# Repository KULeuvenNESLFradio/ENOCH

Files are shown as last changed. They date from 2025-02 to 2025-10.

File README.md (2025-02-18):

# ENOCH: ENabling On-body Network Contention Handling

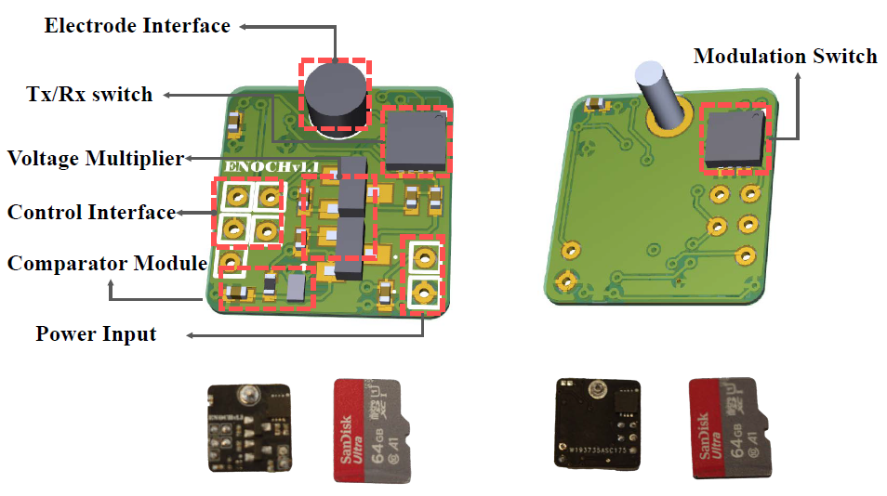
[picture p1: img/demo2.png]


## 📄 Citation
If you use this work, please cite:
ENOCH: ENabling On-body Network Contention Handling  
Mengyao Liu, Jonathan Oostvogels, Bingwu Fang, Sam Michiels, Haoxiang Ma, Yang Yang, and Danny Hughes  
In *Proceedings of the IEEE International Conference on Pervasive Computing and Communications (PerCom)*,  
Washington, DC, USA, March 17–21, 2025. IEEE, 2025.

### 📚 BibTeX
```bibtex
@inproceedings{Liu2025ENOCH,
  author       = {Mengyao Liu and Jonathan Oostvogels and Bingwu Fang and Sam Michiels and Haoxiang Ma and Yang Yang and Danny Hughes},
  title        = {{ENOCH: ENabling On-body network Contention Handling}},
  booktitle    = {Proceedings of the IEEE International Conference on Pervasive Computing and Communications (PerCom)},
  year         = {2025},
  organization = {IEEE},
  address      = {Washington, DC, USA},
  month        = {March},
  pages        = {17--21},
  doi          = {10.1109/PerCom2025.XXXX}  % 请在 DOI 可用时添加
}
```

## Overview
ENOCH is a low-latency, capacitively coupled on-body communication system optimized for ultra-low-power operation. It employs off-the-shelf components and is programmed on an **Arduino Due**, making it accessible for researchers and developers interested in **body area networks (BANs)**.

This repository contains all necessary files to **replicate and extend** our implementation, including:
- Hardware schematics and PCB design files
- Arduino source code and API documentation
- Experimental setups and results

## 🛠 Hardware Setup
### Component Specifications
- **Greinacher Voltage Multiplier:** A capacitive charge-pump circuit optimized for RF signal rectification.
- **Comparator with RC Low-Pass Filter:** Dynamically adjusts thresholds to enhance noise immunity.
- **RF Switches:** ADG918 (TX/RX switching) and ADG902 (OOK modulation).
- **Arduino Due:** Serves as the processing unit for signal transmission and reception.

### PCB Design
The **hardware folder** contains:
- **Schematics** (`.sch`) and **PCB layout files** (`.pcbdoc`)
- **Gerber files** for manufacturing
- **Altium Designer project files**

Manufacturing can be done via [PCBWay](https://www.pcbway.com/). We recommend using the **evaluation board** before transitioning to the miniaturized version.

## 💻 Software Setup
### Requirements
1. Install the [Arduino IDE](https://www.arduino.cc/en/software)
2. Download this repository
3. Connect **Arduino Due** via USB

### Compiling & Uploading
1. Open `Arduino IDE`
2. Select **Arduino Due (Programming Port)** under `Tools → Board`
3. Open `enochtx.ino` or `enochrx.ino`
4. Click `Verify (✔)` and then `Upload (⬆)`
5. Open `Serial Monitor` to view output

## 📡 ENOCH API
To use ENOCH with an **Arduino Due**, define the following pins:
```cpp
#define ENOCHTxCarrier 7     // Tx carrier frequency pin
#define ENOCHOOKSW 2         // Modulation (OOK) Switch pin
#define ENOCHRxGPIO 6        // Rx GPIO pin
#define ENOCHTxRxSwitch 8    // Switch for Tx/Rx mode
```
### Available Functions
```cpp
void Send_preamble(int cycles); // Transmit preamble
void Send_bytes(byte bytex[]);  // Send data bytes
void Read_bytes(byte load[]);   // Read received bytes
boolean checkRxStatus();        // Check channel availability
```

## ⚡ Experiments 
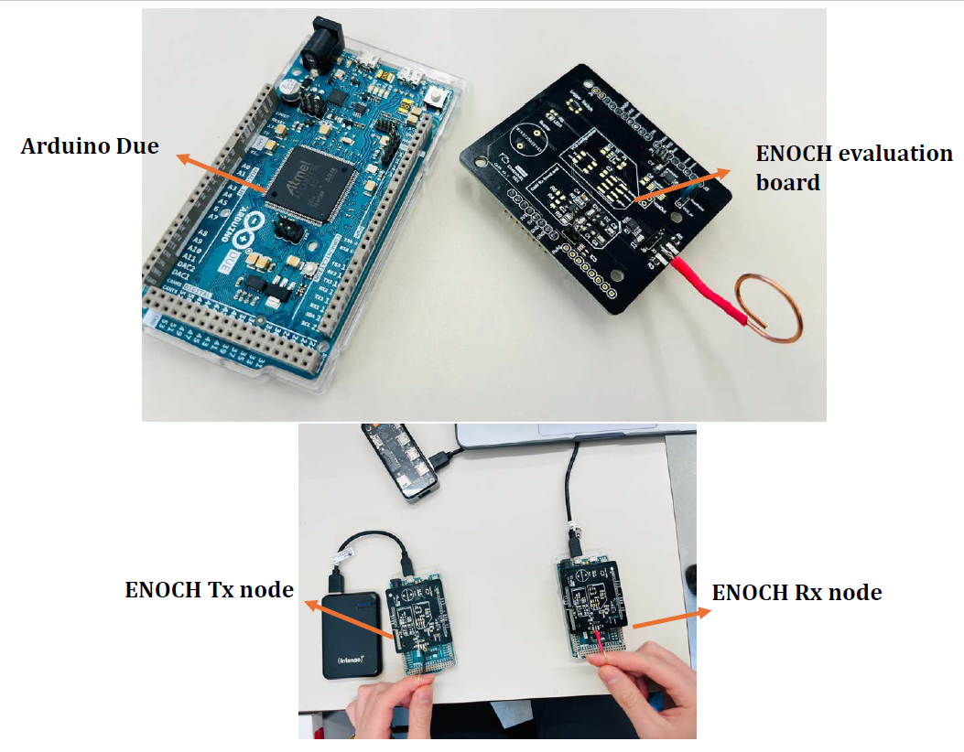
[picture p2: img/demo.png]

### 1️⃣ Single Transmitter & Receiver
- One **ENOCH board** transmits, the other receives.
- The receiver outputs data via `Serial Monitor`.
- **Evaluate packet delivery reliability** by testing different body placements (wrist, arm, ankle).

### 2️⃣ Multi-Node Contention
- Multiple nodes attempt to transmit simultaneously.
- A **hardware trigger button** ensures synchronized transmission.
- Transmission priority is determined by `Send_preamble(int cycles)`.

## 📂 Repository Structure
```
ENOCH/
├── Hardware/       # PCB schematics, Gerber files, and Altium projects
├── Software/       # Arduino source code for Tx and Rx
├── Docs/           # Additional documentation and experiments
├── README.md       # This file
```

## 📬 Contact & Contribution
Feel free to **open an issue** for questions or contributions. We welcome pull requests to improve the ENOCH project!

📧 Contact: [mengyao.liu@kuleuven.be](mailto:mengyao.liu@kuleuven.be)

## 🔗 Links
- 🔬 **Paper:** [PerCom 2025](https://www.percom.org/)
- 📖 **GitHub Repo:** [ENOCH Project](https://github.com/KULeuvenNESLFradio/ENOCH)
- 🏭 **PCB Manufacturing:** [PCBWay](https://www.pcbway.com/)

---
🚀 *Bringing robust on-body network contention handling to ultra-low-power systems!*

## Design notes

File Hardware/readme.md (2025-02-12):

### Component Specifications
- **Greinacher Voltage Multiplier:** A capacitive charge-pump circuit optimized for RF signal rectification.
- **Comparator with RC Low-Pass Filter:** Dynamically adjusts thresholds to enhance noise immunity.
- **RF Switches:** ADG918 (TX/RX switching) and ADG902 (OOK modulation).
- **Arduino Due:** Serves as the processing unit for signal transmission and reception.

### PCB Design
The **hardware folder** contains:
- **Schematics** (`.sch`) and **PCB layout files** (`.pcbdoc`)
- **Gerber files** for manufacturing
- **Altium Designer project files**

### Main Components on the ENOCH Transceiver
| **CAIN Prototype Components** | **Part Number**  | **Purchase Link** |
|---:|:---:|:---:|
| Rectifying Diodes | SMS7630-005LF | [Digi-Key](https://www.digikey.com/en/products/detail/???/???) |
| RF SPDT Switche | ADG918 | [Mouser](https://www.mouser.com/ProductDetail/???/???) |
| RF SPST Switche | ADG902 | [Mouser](https://www.mouser.com/ProductDetail/???/???) |
| Analog Comparator | TLV7031 | [Mouser](https://www.mouser.com/ProductDetail/???/???) |
---
Manufacturing can be done via [PCBWay](https://www.pcbway.com/). We recommend using the **evaluation board** before transitioning to the miniaturized version.

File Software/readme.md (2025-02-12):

# ENOCH Wireless Communication Setup

## 1. Single Transmitter, Single Receiver
Two ENOCH boards are used, each programmed for either transmission (`ENOCHtx.ino`) or reception (`ENOCHrx.ino`).

- The RX board is worn on the finger and connected to a laptop via USB to provide serial data output.
- To assess packet delivery ratio reliability, the TX board can be positioned at various body locations (e.g., wrist, arm, ankle).

## 2. Multiple Transmitters, Single Receiver
In this setup, an additional Arduino trigger board is required to synchronize transmissions across multiple ENOCH nodes.

### Required Components
- ENOCH nodes
- Arduino trigger board
- A button (for generating interrupt signals)

### Steps for Multi-Node Transmission
1. **Set Up the Trigger**
   - Connect a button to the Arduino trigger board and ENOCH nodes.
   - Refer to `trigger_gpio.ino` for implementation details.

2. **Configure ENOCH Transceivers**
   - Load the firmware to enable transmission upon receiving an interrupt signal.
   - Press the button to synchronize transmissions across multiple nodes.

3. **Adjust Priorities (if needed)**
   - Modify `Send_preamble(int cycles)` to assign more cycles to higher-priority nodes.

4. **Test and Verify**
   - Read the received data from the RX board.
   - Check the serial port for transmission logs to validate successful communication.

### Example Code: Button-triggered Transmission
```cpp
#define buttonPin 53 

void buttonISR() {
    buttonPressed = true;
    FristTrigger = true;
    digitalWriteDirect(ENOCHTxRxSwitch, LOW);
    Send_preamble(x);
}  

if (buttonPressed) { 
    do {
        if (checkRxStatus() != RX_BUSY) {
            if (FristTrigger) {
                digitalWriteDirect(ENOCHTxRxSwitch, LOW); 
                Send_bytes('0', 'N', 'O', 'D', 'E', '0', '0');
                digitalWriteDirect(ENOCHTxRxSwitch, HIGH);
                FristTrigger = false;
                buttonPressed = false;
            } else {
                FristTrigger = false;
                digitalWriteDirect(ENOCHTxRxSwitch, LOW);
                Send_preamble(10);
                if (checkRxStatus() != RX_BUSY) {
                    digitalWriteDirect(ENOCHTxRxSwitch, LOW); 
                    Send_bytes('0', 'N', 'O', 'D', 'E', '0', '0');
                    digitalWriteDirect(ENOCHTxRxSwitch, HIGH);
                    buttonPressed = false;
                }
            }
        } 
    } while (buttonPressed);
    Serial.println("Finish sending packets");
}
```

---
For more details, refer to the implementation files (`ENOCHtx.ino`, `ENOCHrx.ino`, `trigger_gpio.ino`).

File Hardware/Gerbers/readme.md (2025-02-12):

-  **CaINV2.2**: Our evaluation board design.
-  **BodyCaINv0.1Gerber**: Adapted to the GEMMA V2 interface.
-  **ENOCHv1.0**: The most miniaturized design.
-  **GerberBodyCaINseedv0.2**: Adapted to the Seeed Studio nRF52840

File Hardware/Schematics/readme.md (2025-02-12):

- **CaINv2.2**: Our evaluation board design.
- **bodyCaINCir**: Adapted to the GEMMA V2 interface.
- **ENOCHv1.0**: The most miniaturized design.

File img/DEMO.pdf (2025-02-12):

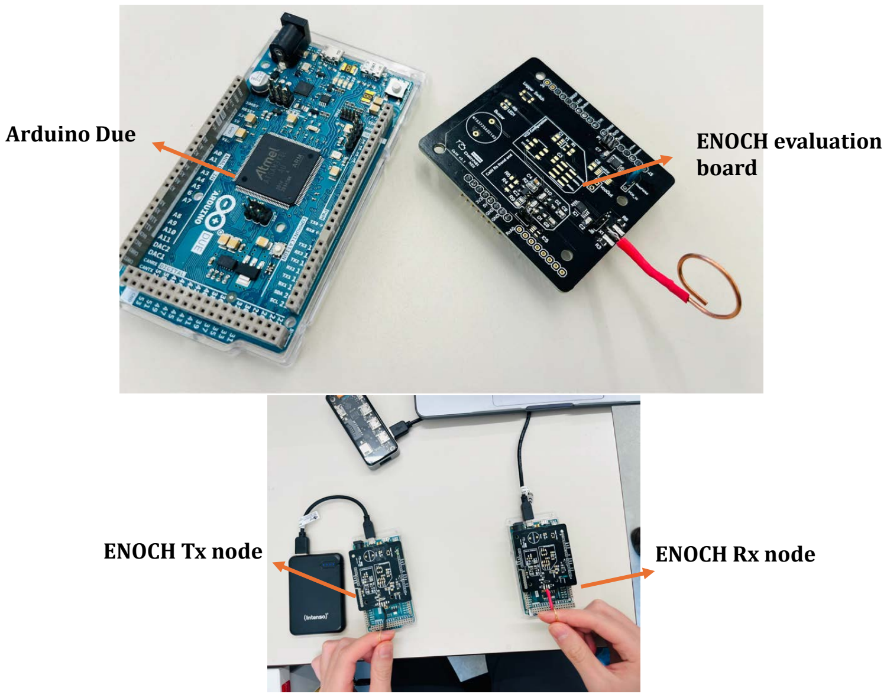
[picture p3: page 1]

Arduino Due | ENOCH evaluation board
ENOCH Tx node | ENOCH Rx node

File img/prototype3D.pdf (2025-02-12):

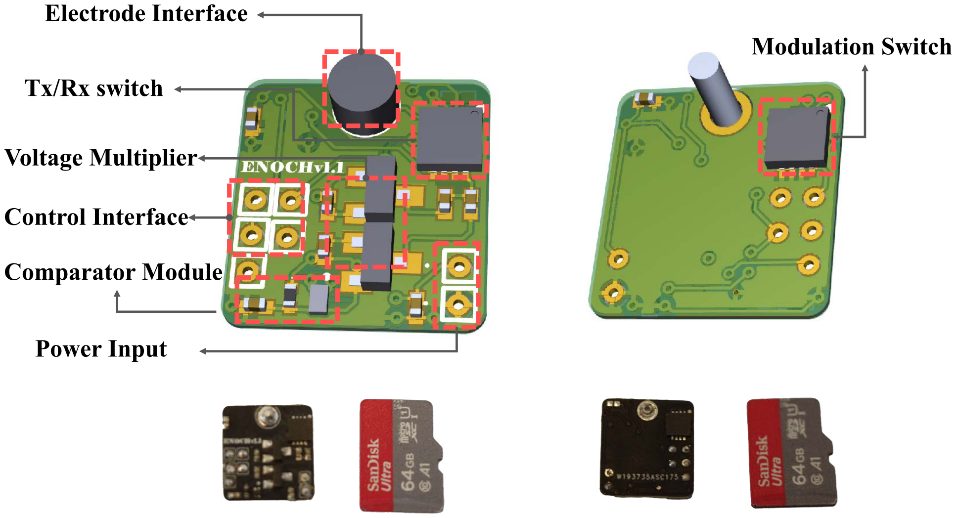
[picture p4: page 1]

Electrode Interface

Tx/Rx switch

Control Interface

Voltage Multiplier

Power Input

Comparator Module

Modulation Switch

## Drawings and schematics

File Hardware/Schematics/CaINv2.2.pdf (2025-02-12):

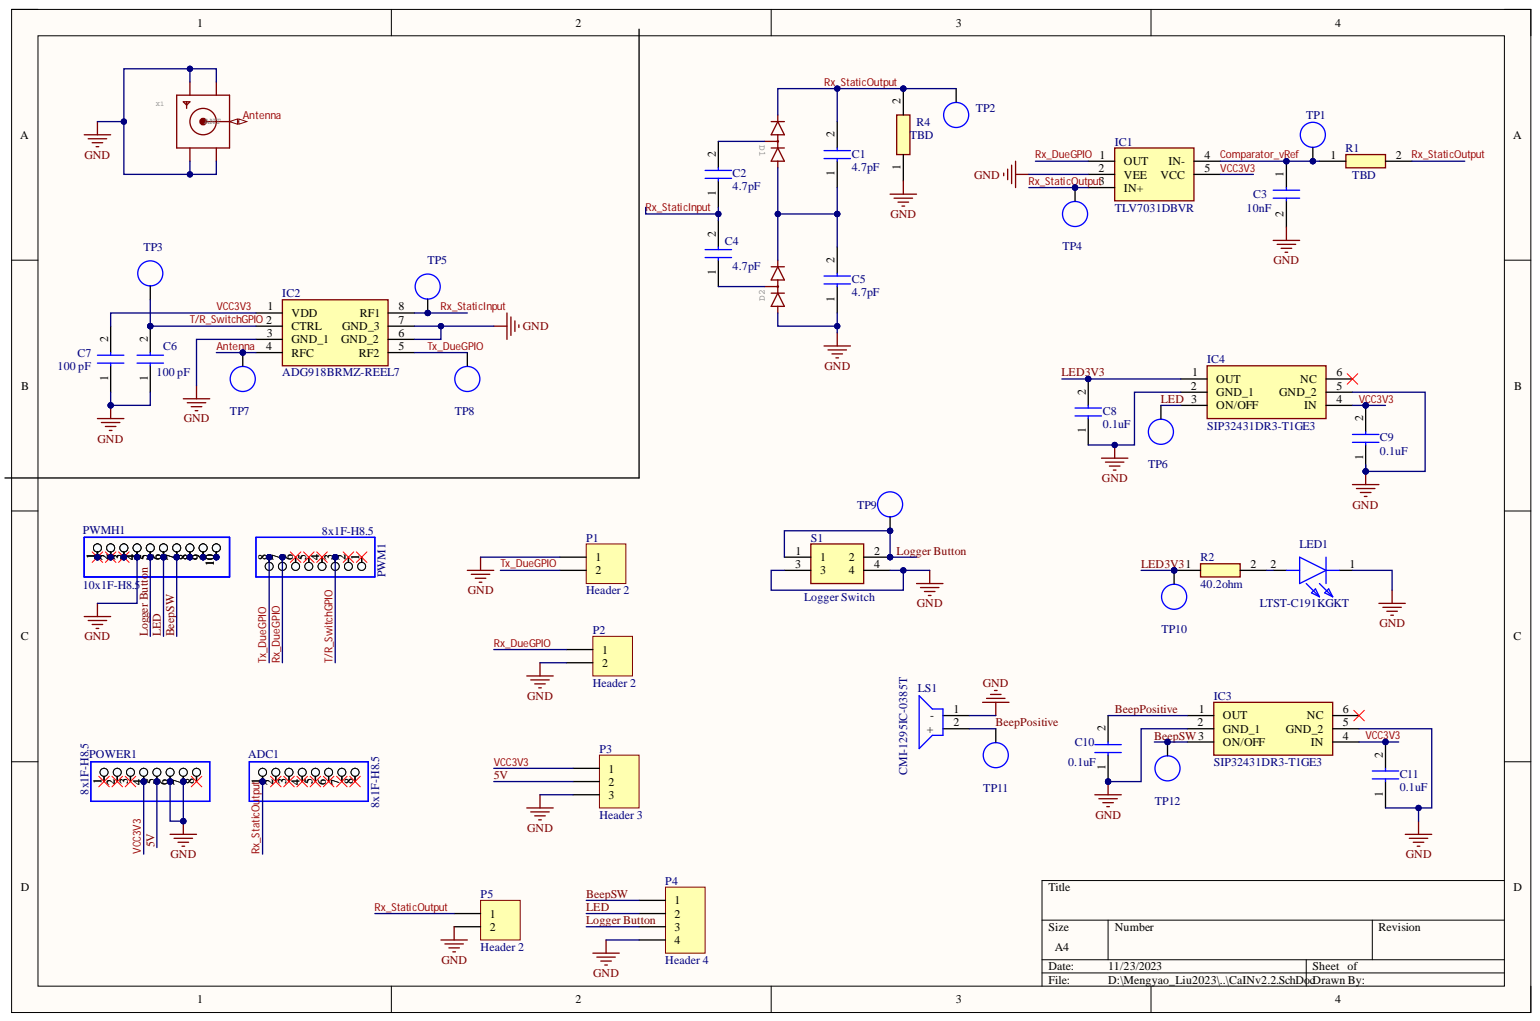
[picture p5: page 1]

GND_1 3 | Tx_DueGPIO

Antenna | RFC 4

GND_1 2

BeepSW | ON/OFF 3 | VCC3V3 C11

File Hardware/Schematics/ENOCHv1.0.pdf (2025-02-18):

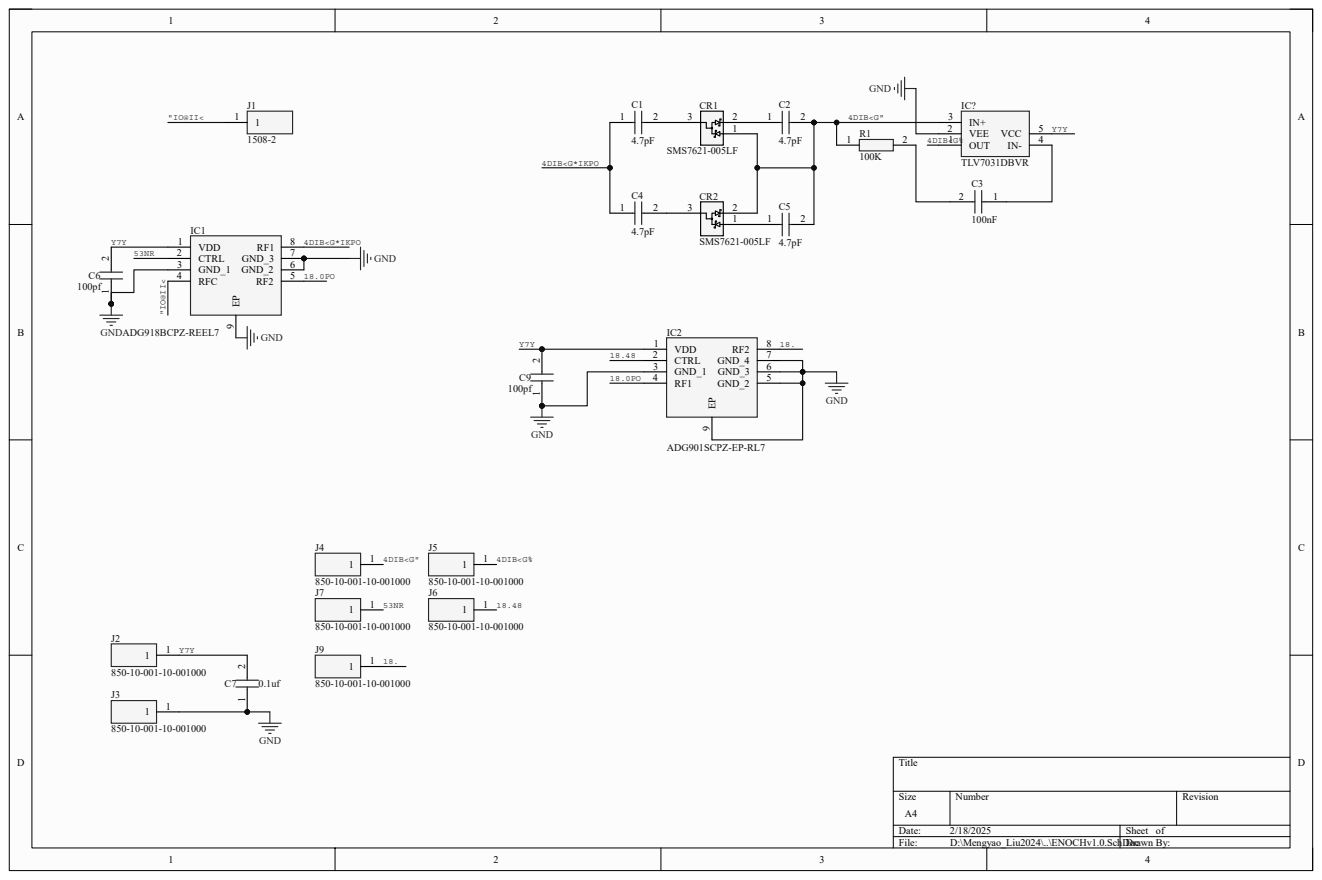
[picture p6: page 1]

Size A4 | Number | Revision

Date: 2/18/2025 | Sheet of
File: D:\Mengyao_Liu2024\..\ENOCHv1.0.SchDoc Drawn By:

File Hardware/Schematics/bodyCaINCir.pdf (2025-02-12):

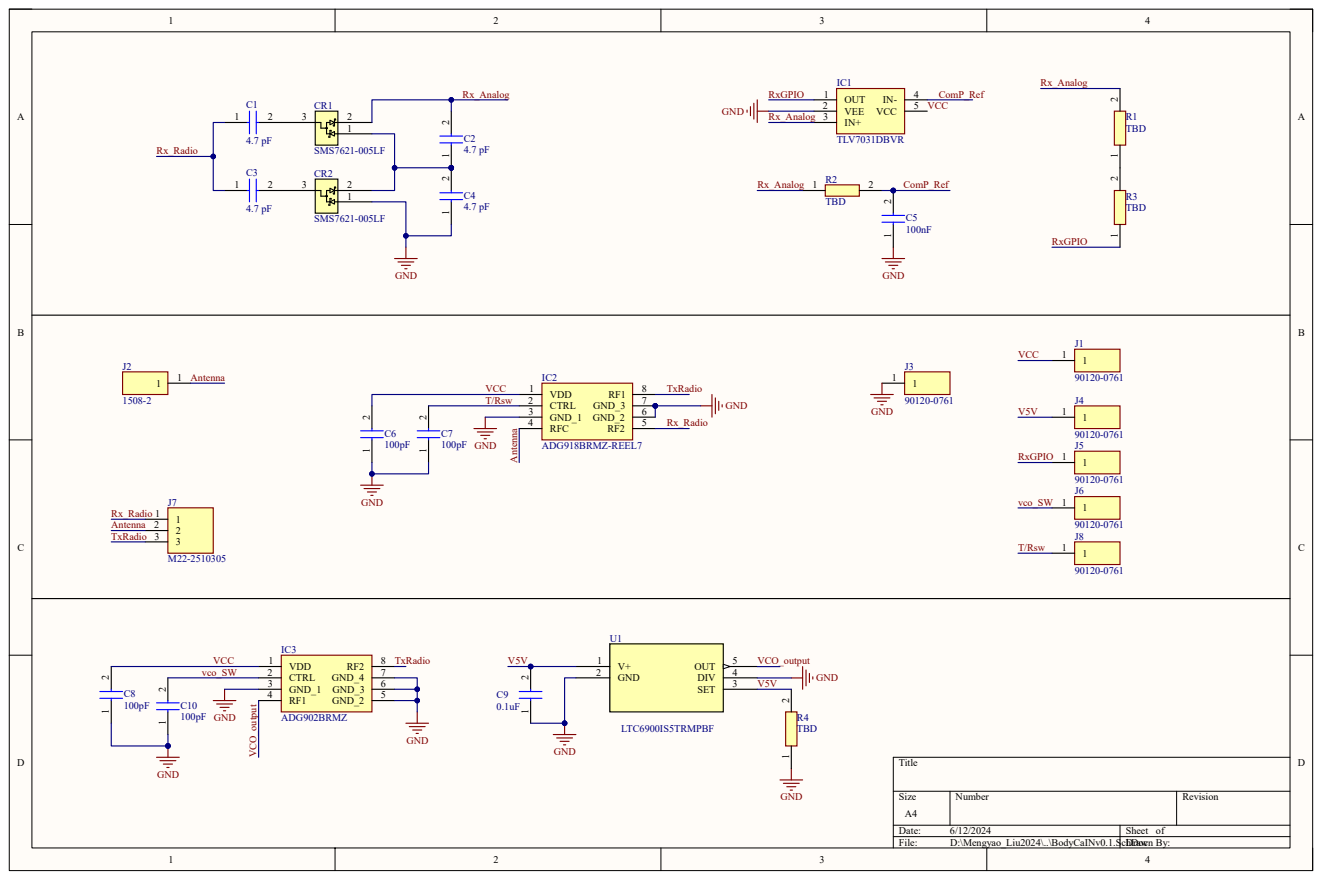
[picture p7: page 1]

Size A4 | Number | Revision

Date: 6/12/2024 | Sheet of
File: D:\Mengyao_Liu2024\..\BodyCaINv0.1.SchDoc Drawn By:

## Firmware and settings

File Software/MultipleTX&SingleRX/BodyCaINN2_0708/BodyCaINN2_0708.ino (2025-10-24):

#define CaINTxGPIO PIO_PC23B_PWML6  
#define CaINTxRxSwitch 8 
#define CaINOPWMSW 2
#define CaINRxGPIO 6 
#define buttonPin 53
#define OnRadioFlag HIGH
#define OffRadioFlag LOW

/* Generate the PWM (12 MHz) */
const uint8_t BitRate20khz = 80;
const uint8_t Period12Mhz = 2;
const uint8_t Duty12Mhz = 1;

volatile bool buttonPressed = false; 
volatile bool firstTrigger = false;
volatile uint8_t Preambletimes = 0;
byte Address_Node[8] = { 0, 0, 1, 0, 0, 1, 0, 1 };
volatile boolean TxState ;

inline boolean digitalWriteDirect(int pin, boolean val) {
  if (val) g_APinDescription[pin].pPort -> PIO_SODR = g_APinDescription[pin].ulPin;
  else    g_APinDescription[pin].pPort -> PIO_CODR = g_APinDescription[pin].ulPin;
  if (val == HIGH) return OnRadioFlag;
  else return OffRadioFlag;
}

inline int digitalReadDirect(int pin) {
  return !!(g_APinDescription[pin].pPort -> PIO_PDSR & g_APinDescription[pin].ulPin);
}


// Generate the PWM (12 MHz) as Carrier Frequency From 38.6.5 PWM Controller Operations //
void Enable_CarrierPWM(uint8_t Period, uint8_t Duty) {
  /* Activate clock for PWM controller from PMC, PWM ID =36 ->*/
  REG_PMC_PCER1 = 1 << 4;
  // Activate peripheral functions for pin -> Datasheet 31.7.2 & 31.5.2&3)
  REG_PIOC_PDR |= CaINTxGPIO;
  REG_PIOC_ABSR |= CaINTxGPIO;
  /*   ----------------The following is for configure the PWM ----------------*/
  //38.7.1 Select the MCK (Master clock 84Mhz)
  REG_PWM_CLK = 0;
  //38.7.37 PWM Channel Mode Register PWM channel 6 (pin7) -> (CPOL = 0)  left-aligned
  REG_PWM_CMR6 = 0 << 9;
  //38.7.40 PWM Channel Period Register (16 bits -> Period / 84 = Frequency Output )
  REG_PWM_CPRD6 = Period;
  //38.7.38 PWM Channel Duty Cycle Register
  REG_PWM_CDTY6 = Duty;
  //38.7.2 PWM Enable Register
  REG_PWM_ENA = 1 << 6;
  //  return OnRadioFlag;
}

void Ascii_to_BinaryAarray(char ascii, uint8_t arr[8]) {
  //Serial.print(ascii);
  byte mask = 0b00000001;
  for (int i = 0; i < 8; i++) {
    arr[i] = ascii & mask;
    arr[i] = arr[i] >> i;
    mask = mask << 1;
  }
}

/*send  HIGH LOW edges to synchronize with the receptor*/
void Send_sync(int cycles) {
  //sending a sync signal
  for (byte i = 0; i < cycles; i++) {
    digitalWriteDirect(CaINOPWMSW, HIGH);
    delayMicroseconds(BitRate20khz);
    digitalWriteDirect(CaINOPWMSW, LOW);
    delayMicroseconds(BitRate20khz);
  }
  digitalWriteDirect(CaINOPWMSW, HIGH);
}

///*send  HIGH LOW edges to synchronize with the receptor*/
void Send_preamble(int cycles) {
  for (byte i = 0; i < cycles; i++) {
    digitalWriteDirect(CaINOPWMSW, HIGH);
    delayMicroseconds(BitRate20khz/2);
    digitalWriteDirect(CaINOPWMSW, LOW);
    delayMicroseconds(BitRate20khz/2);
  }
  digitalWriteDirect(CaINOPWMSW, LOW);
}


/*send a byte but without sync; state is the current state of the ouput line*/
boolean Send_load(byte Databits[], boolean Bitstate) {
  for (byte i = 0; i < 8; i++) {
    //Serial.print(start[i]);
    if (Databits[i] == 1) {
      if (Bitstate == LOW)
      {
        delayMicroseconds(BitRate20khz);
        Bitstate = digitalWriteDirect(CaINOPWMSW, HIGH);
      }
      else 
      {
        delayMicroseconds(BitRate20khz / 2);
        digitalWriteDirect(CaINOPWMSW, LOW);
        delayMicroseconds(BitRate20khz / 2);
        Bitstate = digitalWriteDirect(CaINOPWMSW, HIGH);
      }
    }
    else  
    {
      if (Bitstate == LOW)
      {
        delayMicroseconds(BitRate20khz / 2);
        digitalWriteDirect(CaINOPWMSW, HIGH);
        delayMicroseconds(BitRate20khz / 2);
        Bitstate = digitalWriteDirect(CaINOPWMSW, LOW);
      }
      else  
      {
        delayMicroseconds(BitRate20khz);
        Bitstate = digitalWriteDirect(CaINOPWMSW, LOW);
      }
    }
  }
  return Bitstate;
}

/*send a sync signal + a start byte + load ; load is an array of 8 bit, no more no less !!*/
void Send_bytes(byte byteload0, byte byteload1, byte byteload2, byte byteload3, byte byteload4, byte byteload5, byte byteload6) {

  byte Dataload0Arr[8];
  byte Dataload1Arr[8];
  byte Dataload2Arr[8];
  byte Dataload3Arr[8];
  byte Dataload4Arr[8];
  byte Dataload5Arr[8];
  byte Dataload6Arr[8];

  Ascii_to_BinaryAarray(byteload0, Dataload0Arr);    //change ascii code to bits array
  Ascii_to_BinaryAarray(byteload1, Dataload1Arr);    //change ascii code to bits array
  Ascii_to_BinaryAarray(byteload2, Dataload2Arr);
  Ascii_to_BinaryAarray(byteload3, Dataload3Arr);
  Ascii_to_BinaryAarray(byteload4, Dataload4Arr);
  Ascii_to_BinaryAarray(byteload5, Dataload5Arr);
  Ascii_to_BinaryAarray(byteload6, Dataload6Arr);

  // Send 32 cycles for preamble
  Send_sync(10);
  //line must be high after sync
  TxState = HIGH;
  TxState = Send_load(Address_Node, TxState);
  TxState = HIGH;
  TxState = Send_load(Dataload0Arr, TxState);
  TxState = Send_load(Dataload1Arr, TxState);
  TxState = Send_load(Dataload2Arr, TxState);
  TxState = Send_load(Dataload3Arr, TxState);
  TxState = Send_load(Dataload4Arr, TxState);
  TxState = Send_load(Dataload5Arr, TxState);
  TxState = Send_load(Dataload6Arr, TxState);
  digitalWriteDirect(CaINOPWMSW, LOW);
}


// #define TIMEOUT_IDLE 180
// #define THRESHOLD_BUSY_1 60
// #define THRESHOLD_BUSY_2 100
// #define RX_BUSY true
// #define RX_IDLE false

#define TIMEOUT_IDLE 170
#define THRESHOLD_BUSY_1 50
#define THRESHOLD_BUSY_2 80
#define RX_BUSY true
#define RX_IDLE false

boolean checkRxStatus() {
  long startTime = micros();  // Record the start time
  boolean initialState = digitalReadDirect(CaINRxGPIO);  // Read the initial state
  long elapsedTime;
  boolean currentRxState;

  while (true) {
    currentRxState = digitalReadDirect(CaINRxGPIO);  // Read the current state
    
    if (currentRxState != initialState) {  // State has changed
      
      elapsedTime = micros() - startTime;  // Calculate elapsed time
      if (elapsedTime < THRESHOLD_BUSY_2) {
        return RX_BUSY;  // Busy: state change time is less than 50 microseconds
      } 
      initialState = currentRxState;
      startTime = micros();
    }
    if ((micros() - startTime) > TIMEOUT_IDLE) {
      return RX_IDLE;  // Idle: no state change for more than 120 microseconds
    }
  }
}


//#define TIMEOUT_IDLE1 270
//#define THRESHOLD_BUSY_11 60
//#define THRESHOLD_BUSY_21 110
//#define RX_BUSY1 true
//#define RX_IDLE1 false
//
//boolean checkRxStatus1() {
//  
//  long startTime = micros();  // Record the start time
//  boolean initialState = digitalReadDirect(CaINRxGPIO);  // Read the initial state
//  long elapsedTime;
//  boolean currentRxState;
//
//  while (true) {
//    currentRxState = digitalReadDirect(CaINRxGPIO);  // Read the current state
//    
//    if (currentRxState != initialState) {  // State has changed
//      
//      elapsedTime = micros() - startTime;  // Calculate elapsed time
//      if (elapsedTime < THRESHOLD_BUSY_21) {
//        return RX_BUSY1;  // Busy: state change time is less than 50 microseconds
//      } 
//      initialState = currentRxState;
//      startTime = micros();
//    }
//    if ((micros() - startTime) > TIMEOUT_IDLE1) {
//      return RX_IDLE1;  // Idle: no state change for more than 120 microseconds
//    }
//  }
//}

#define TIMEOUT_IDLE0 80
#define THRESHOLD_BUSY_10 30
#define THRESHOLD_BUSY_20 80
#define RX_BUSY0 true
#define RX_IDLE0 false

boolean checkRxStatus0() {
  long startTime = micros();  // Record the start time
  boolean initialState = digitalReadDirect(CaINRxGPIO);  // Read the initial state
  long elapsedTime;
  boolean currentRxState;
  
  while (true) {
    currentRxState = digitalReadDirect(CaINRxGPIO);  // Read the current state
    
    if (currentRxState != initialState) 
    {  // State has changed    
        elapsedTime = micros() - startTime;  // Calculate elapsed time
        if (elapsedTime < THRESHOLD_BUSY_20) {
          return RX_BUSY;  // Busy: state change time is less than 50 microseconds
        }
//        else if (elapsedTime > THRESHOLD_BUSY_3) 
//          return RX_IDLE;
//      // Update the initial state and start time
      initialState = currentRxState;
      startTime = micros();
   }
    if ((micros() - startTime) > TIMEOUT_IDLE0) 
    {
      return RX_IDLE;  // Idle: no state change for more than 120 microseconds
    }
  }
}


void sendData() {
    digitalWriteDirect(CaINTxRxSwitch, LOW);
    Send_bytes('2', 'N', 'O', 'D', 'E', '2', '2');
    digitalWriteDirect(CaINTxRxSwitch, HIGH);
}

void sendPreamble() {
    digitalWriteDirect(CaINTxRxSwitch, LOW);
    Send_preamble(8);
    digitalWriteDirect(CaINTxRxSwitch, HIGH);
}

// Interrupt service routine for the button press
void buttonISR() {
    buttonPressed = true;
    firstTrigger = true ;
}


void setup() {
  // put your setup code here, to run once:
  Serial.begin(250000);
  Serial.println("Welcome to seth2");
  pinMode(CaINRxGPIO,INPUT); 
  pinMode(CaINTxRxSwitch,OUTPUT); 
  pinMode(CaINOPWMSW, OUTPUT);
  pinMode(buttonPin, INPUT);
  attachInterrupt(digitalPinToInterrupt(buttonPin), buttonISR, RISING);
  Enable_CarrierPWM(Period12Mhz, Duty12Mhz);
  digitalWriteDirect(CaINOPWMSW, LOW); 
  digitalWriteDirect(CaINTxRxSwitch, HIGH);
}

void loop() {
  // put your main code here, to run repeatedly:
  if (buttonPressed){
     sendPreamble(); 
    do{ 
        if (checkRxStatus() != RX_BUSY)
        { 
          if(firstTrigger){
            sendData();
            firstTrigger = false;
            buttonPressed = false ;
          }
          else{
            Preambletimes =1;
            sendPreamble();
            while (checkRxStatus() == RX_BUSY);
            sendPreamble();
            Preambletimes =2;
            while (checkRxStatus0() == RX_BUSY0);
            if(Preambletimes == 2)
            {
              sendData();
              Preambletimes = 0;
              buttonPressed = false ;
            }
        }
      }
      firstTrigger = false;
    }
    while (buttonPressed);
  }
 }

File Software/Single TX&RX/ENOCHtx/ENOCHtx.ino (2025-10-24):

#define CaINTxGPIO PIO_PC23B_PWML6  //  DigitalPin 7 -> PC23 PWML6_PC23 => PWM_CH6
#define CaINOPWMSW 2
#define CaINRxGPIO 6
#define CaINTxRxSwitch 8
#define OnRadioFlag HIGH
#define OffRadioFlag LOW

const uint32_t BitRate5khz = 200;
const uint8_t BitRate1khz = 1;

/* Generate the PWM (42 MHz) */
const uint8_t Period42Mhz = 2;
const uint8_t Duty42Mhz = 1;

byte Address_Node0[8] = { 0, 1, 1, 0, 0, 1, 0, 1 };
byte Address_Node1[8] = { 0, 0, 1, 0, 0, 1, 0, 1 };
byte Address_Node2[8] = { 0, 0, 1, 0, 1, 1, 0, 1 };
byte Address_Node3[8] = { 0, 1, 0, 0, 1, 1, 0, 1 };
byte Address_Node4[8] = { 0, 1, 1, 0, 1, 0, 1, 1 };
byte Address_Node5[8] = { 0, 0, 1, 1, 0, 0, 1, 1 };
volatile boolean state;

inline boolean digitalWriteDirect(int pin, boolean val) {
  if (val) g_APinDescription[pin].pPort -> PIO_SODR = g_APinDescription[pin].ulPin;
  else    g_APinDescription[pin].pPort -> PIO_CODR = g_APinDescription[pin].ulPin;
  if (val == HIGH) return OnRadioFlag;
  else return OffRadioFlag;
}

inline int digitalReadDirect(int pin) {
  return !!(g_APinDescription[pin].pPort -> PIO_PDSR & g_APinDescription[pin].ulPin);
}


// ------------------------------------------------------------------------
// Trun on the Radio
// ------------------------------------------------------------------------
// Generate the PWM (42 MHz) as Carrier Frequency From 38.6.5 PWM Controller Operations //
// pin_traits_specialization(pwm_pin::PWML6_PC23, PIOC, PIO_PC23B_PWML6, ID_PIOC, PIO_PERIPH_B, PIO_DEFAULT,  PWM_CH6,true  );
void Enable_CarrierPWM(uint8_t Period, uint8_t Duty) {
  /* Activate clock for PWM controller from PMC, PWM ID =36 ->*/
  REG_PMC_PCER1 = 1 << 4;
  // Activate peripheral functions for pin -> Datasheet 31.7.2 & 31.5.2&3)
  REG_PIOC_PDR |= CaINTxGPIO;
  REG_PIOC_ABSR |= CaINTxGPIO;
  /*   ----------------The following is for configure the PWM ----------------*/
  //38.7.1 Select the MCK (Master clock 84Mhz)
  REG_PWM_CLK = 0;
  //38.7.37 PWM Channel Mode Register PWM channel 6 (pin7) -> (CPOL = 0)  left-aligned
  REG_PWM_CMR6 = 0 << 9;
  //38.7.40 PWM Channel Period Register (16 bits -> Period / 84 = Frequency Output )
  REG_PWM_CPRD6 = Period;
  //38.7.38 PWM Channel Duty Cycle Register
  REG_PWM_CDTY6 = Duty;
  //38.7.2 PWM Enable Register
  REG_PWM_ENA = 1 << 6;
  //  return OnRadioFlag;
}

// Trun off the RF
void Disable_CarrierPWM(void) {
  // Disable all GPIO & peripherals Configuration
  REG_PIOC_PDR = 0;
  REG_PIOC_ABSR = 0;
  // Disable the PWM clock and channel
  REG_PMC_PCDR1 = 1 << 4;
  REG_PWM_DIS = 1 << 6;
  //  return OffRadioFlag;
}

void Ascii_to_BinaryAarray(char ascii, uint8_t arr[8]) {

  //Serial.print(ascii);
  byte mask = 0b00000001;
  for (int i = 0; i < 8; i++) {
    arr[i] = ascii & mask;
    arr[i] = arr[i] >> i;
    mask = mask << 1;
  }
}


/*send 32 HIGH LOW edges to synchronize with the receptor*/
void Send_sync(int cycles) {
  //sending a sync signal
  for (byte i = 0; i < cycles; i++) {
    digitalWriteDirect(CaINOPWMSW, HIGH);
    delayMicroseconds(BitRate5khz);
    digitalWriteDirect(CaINOPWMSW, LOW);
    delayMicroseconds(BitRate5khz);
  }
  digitalWriteDirect(CaINOPWMSW, HIGH);
}

/*send a byte but without sync; state is the current state of the ouput line*/
boolean Send_load(byte start[], boolean state) {
  for (byte i = 0; i < 8; i++) {
    //Serial.print(start[i]);
    if (start[i] == 1) {
      if (state == LOW)
      {
        delayMicroseconds(BitRate5khz);
        state = digitalWriteDirect(CaINOPWMSW, HIGH);
      }
      else  //state==HIGH
      {
        delayMicroseconds(BitRate5khz / 2);
        state = digitalWriteDirect(CaINOPWMSW, LOW);
        delayMicroseconds(BitRate5khz / 2);
        state = digitalWriteDirect(CaINOPWMSW, HIGH);
      }
    }
    else  //start[i]==0
    {
      if (state == LOW)
      {
        delayMicroseconds(BitRate5khz / 2);
        state = digitalWriteDirect(CaINOPWMSW, HIGH);
        delayMicroseconds(BitRate5khz / 2);
        state = digitalWriteDirect(CaINOPWMSW, LOW);
      }
      else  //state==HIGH
      {
        delayMicroseconds(BitRate5khz);
        state = digitalWriteDirect(CaINOPWMSW, LOW);
      }
    }
  }
  return state;
}


/*send a sync signal + a start byte + load ; load is an array of 8 bit, no more no less !!*/
void Send_bytes(byte byteload0, byte byteload1, byte byteload2, byte byteload3, byte byteload4, byte byteload5, byte byteload6) {

  byte Dataload0Arr[8];
  byte Dataload1Arr[8];
  byte Dataload2Arr[8];
  byte Dataload3Arr[8];
  byte Dataload4Arr[8];
  byte Dataload5Arr[8];
  byte Dataload6Arr[8];

  Ascii_to_BinaryAarray(byteload0, Dataload0Arr);    //change ascii code to bits array
  Ascii_to_BinaryAarray(byteload1, Dataload1Arr);    //change ascii code to bits array
  Ascii_to_BinaryAarray(byteload2, Dataload2Arr);
  Ascii_to_BinaryAarray(byteload3, Dataload3Arr);
  Ascii_to_BinaryAarray(byteload4, Dataload4Arr);
  Ascii_to_BinaryAarray(byteload5, Dataload5Arr);
  Ascii_to_BinaryAarray(byteload6, Dataload6Arr);

  // Send 32 cycles for preamble
  Send_sync(32);
  //line must be high after sync
  state = HIGH;
  //send the start message
  state = Send_load(Address_Node0, state);
  state = HIGH;
  state = Send_load(Dataload0Arr, state);
  //Serial.println();
  state = Send_load(Dataload1Arr, state);
  //Serial.println();
  state = Send_load(Dataload2Arr, state);
  //Serial.println();
  state = Send_load(Dataload3Arr, state);
  //Serial.println();
  state = Send_load(Dataload4Arr, state);
  //Serial.println();
  state = Send_load(Dataload5Arr, state);
  //Serial.println();
  //Send_syncEnd(4);
  state = Send_load(Dataload6Arr, state);
  digitalWriteDirect(CaINOPWMSW, LOW);
}

void setup() {
  //Serial.begin(115200);
  Disable_CarrierPWM();
  delay(1);
  Enable_CarrierPWM(Period42Mhz, Duty42Mhz);
  pinMode(CaINOPWMSW, OUTPUT);
  digitalWriteDirect(CaINOPWMSW, HIGH);
  pinMode(CaINTxRxSwitch, OUTPUT);
  digitalWrite(CaINTxRxSwitch, LOW);
  delay(5000);
}

void loop() {
  
  Send_bytes('0', 'A', 'b' , 'C', 's', 'i','0');
  delay(2000);
  Send_bytes('1', 'B', 'b' , 'F', 'f', 'b','1');
  delay(2000);
  Send_bytes('2', 'A', 'n' , 'A', 'd', 'a','2');
  delay(2000);
  Send_bytes('3', 'f', 'g' , 'A', 'B', 's','3');
  delay(2000);
  Send_bytes('4', 'a', 'b' , 'F', 'd', 'A','4');
  delay(2000);
  Send_bytes('5', 'D', 'b' , 'A', 'A', 'b','5');
  delay(2000);
  Send_bytes('6', 'T', 'b' , 'B', 'B', 'b','6');
  delay(2000);
  Send_bytes('7', 'a', 'b' , 'b', 'A', '0','7');
  delay(2000);
  Send_bytes('8', 'a', 'b' , 'i', 'b', 'a','8');
  delay(2000);
  Send_bytes('9', 'B', 'b' , 'A', 'a', 'a','9');
  delay(2000);
  
}
